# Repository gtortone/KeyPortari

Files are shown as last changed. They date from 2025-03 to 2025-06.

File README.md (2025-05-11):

# 🕹️⌨️ The KeyPortari a 2600/7800 Keyboard Interface

This project enables the connection of a PS/2 keyboard (or a USB keyboard that supports the PS/2 protocol) to the Atari 2600 or 7800 console. The ATmega328P processes keystrokes and controls the joystick inputs of the Atari 2600 accordingly.

## ✨ Features
- **PS/2 Keyboard Support**: Supports various keyboard layouts (DE, US, FR).
- **Direct ASCII Conversion**: Translates keystrokes into Atari 2600-compatible signals.
- **Configurable Keymaps**: Customizable key assignments for Atari 2600 control.
- **Efficient GPIO Usage**: Utilizes an 8-bit port for direct control.
- **Configurable DIP Switches**: 4-bit resistor-ladder circuit for easy configuration.

## 🔌 Hardware Requirements
- **ATmega328P 5V 16Mhz (Arduino-compatible)**
- **PS/2 Keyboard (or USB Keyboard that supports the PS/2 protocol)**
- **Resistors for Resistor-Ladder (10kΩ, 20kΩ, 40kΩ, 80kΩ, 100kΩ Pull-up)**
- **2x Quad analog switch (74HC4066)**
- **Joystick port connection for the Atari 2600**

## 🛠️ Sponsored by JLCPCB
PCB manufacturing for this project was kindly sponsored by [JLCPCB](https://jlcpcb.com/?from=KEYPORTARI) – a leading PCB prototype service.
For the first prototype run, [JLCPCB](https://jlcpcb.com/?from=KEYPORTARI) generously provided 15 SMD assembled test boards, helping to accelerate early hardware development.

If you’re a developer or hardware tinkerer and would like to experiment with the interface or contribute your own ideas, feel free to reach out to me via [AtariAge](https://forums.atariage.com/topic/380359-the-keyportari-a-keyboard-interface-for-the-atari-26007800/page/4/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) – I’d be happy to provide a board to support your work.

## 🧪 Breadboard Setup (one joystick forwarded)
Breadboard Setup with one joystick forwarded

## ⚙️ Installation & Setup
1. **Upload code to ATmega328P** (via Arduino IDE or AVRDUDE).
2. **Connect PS/2 keyboard** to the corresponding pins.
3. **Set DIP switches** for the desired configuration.
4. **Connect to the Atari 2600 joystick port**.

## 🎮 Usage
- Each keystroke on the PS/2 keyboard is translated into joystick controls for the Atari 2600.
- Modifier keys like `Shift`, `Ctrl`, and `Alt` influence the key output (e.g., uppercase/lowercase characters).
- DIP switches can be used to activate different keyboard layout (US,DE,FR) configurations.

## 🐞 Known Issues & Solutions

## 🙏 Credits
- Project discussion: [AtariAge Forum](https://forums.atariage.com/topic/380359-keyboard-interface-for-the-atari-2600/)
- Open-source libraries: PS/2 Keyboard Library (modified for this project)
- Steve Guidi's ["Basic Programming" protocol](https://github.com/SteveGuidi/video-companion-media/tree/main/2021.06.09%20-%20Atari%202600%20Keyboard)

## 📄 License
- Firmware is licensed under the [MIT License](LICENSE)
- Hardware designs (schematics, PCB) are under the [CERN Open Hardware Licence v2.0 - Permissive](LICENSE-HARDWARE)

---
If you have any questions or suggestions, feel free to open an issue on GitHub! 🎮

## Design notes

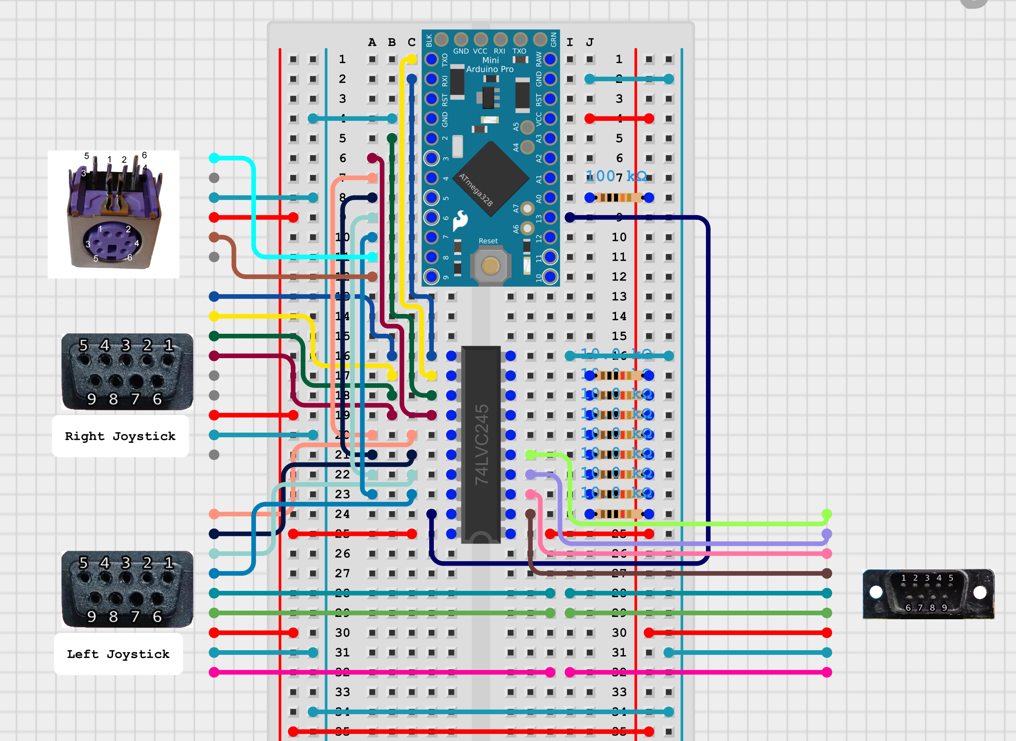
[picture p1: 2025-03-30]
docs/Breadboard_v1.png

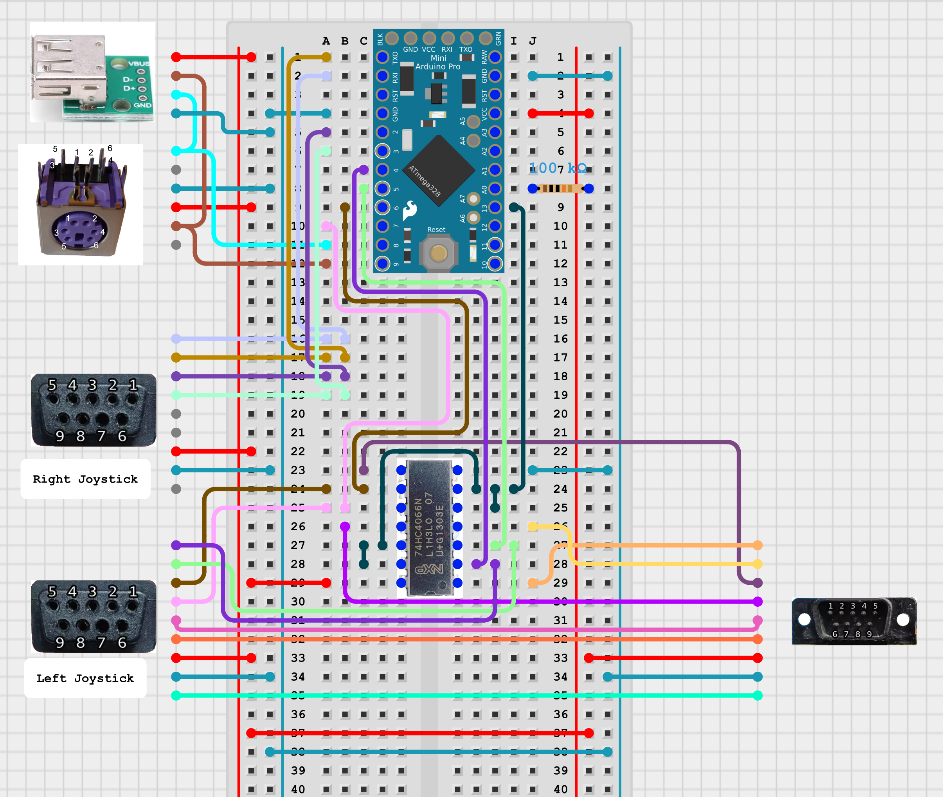
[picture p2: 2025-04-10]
docs/Breadboard_v3.png

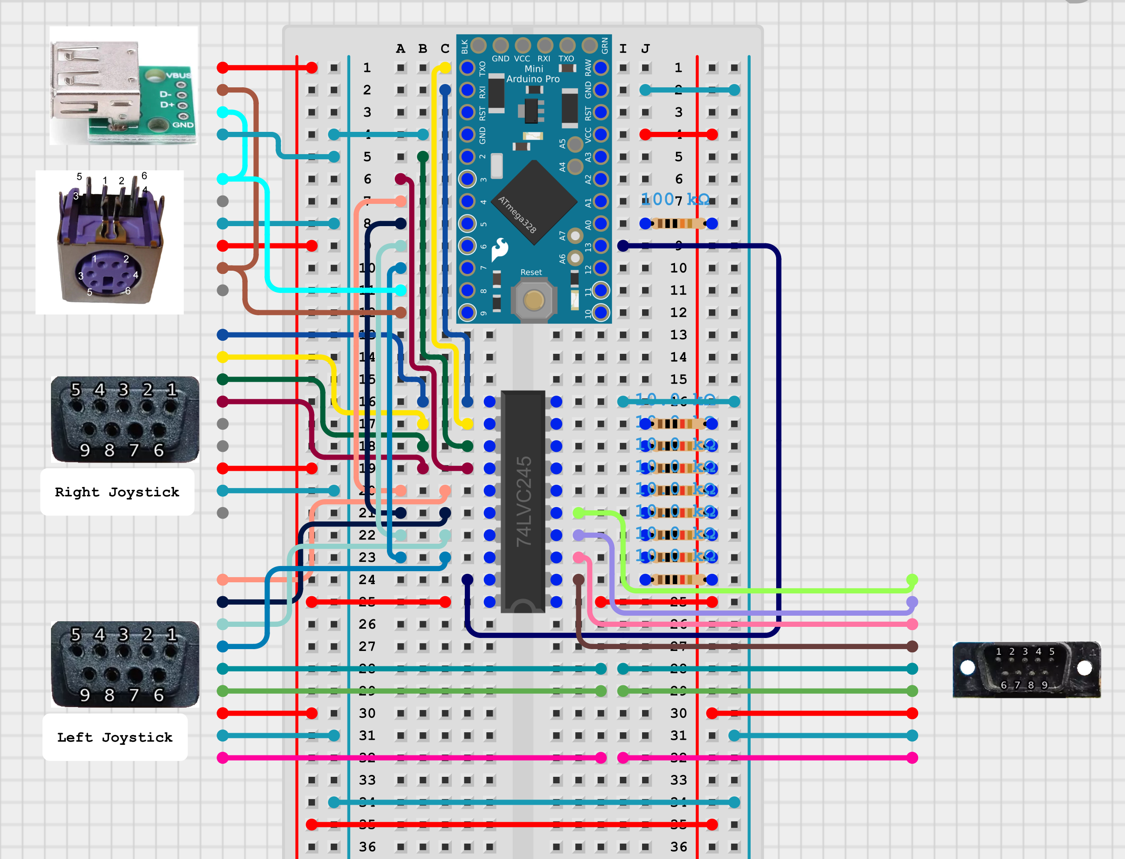
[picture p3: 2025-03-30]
docs/Breadboard_v2.png

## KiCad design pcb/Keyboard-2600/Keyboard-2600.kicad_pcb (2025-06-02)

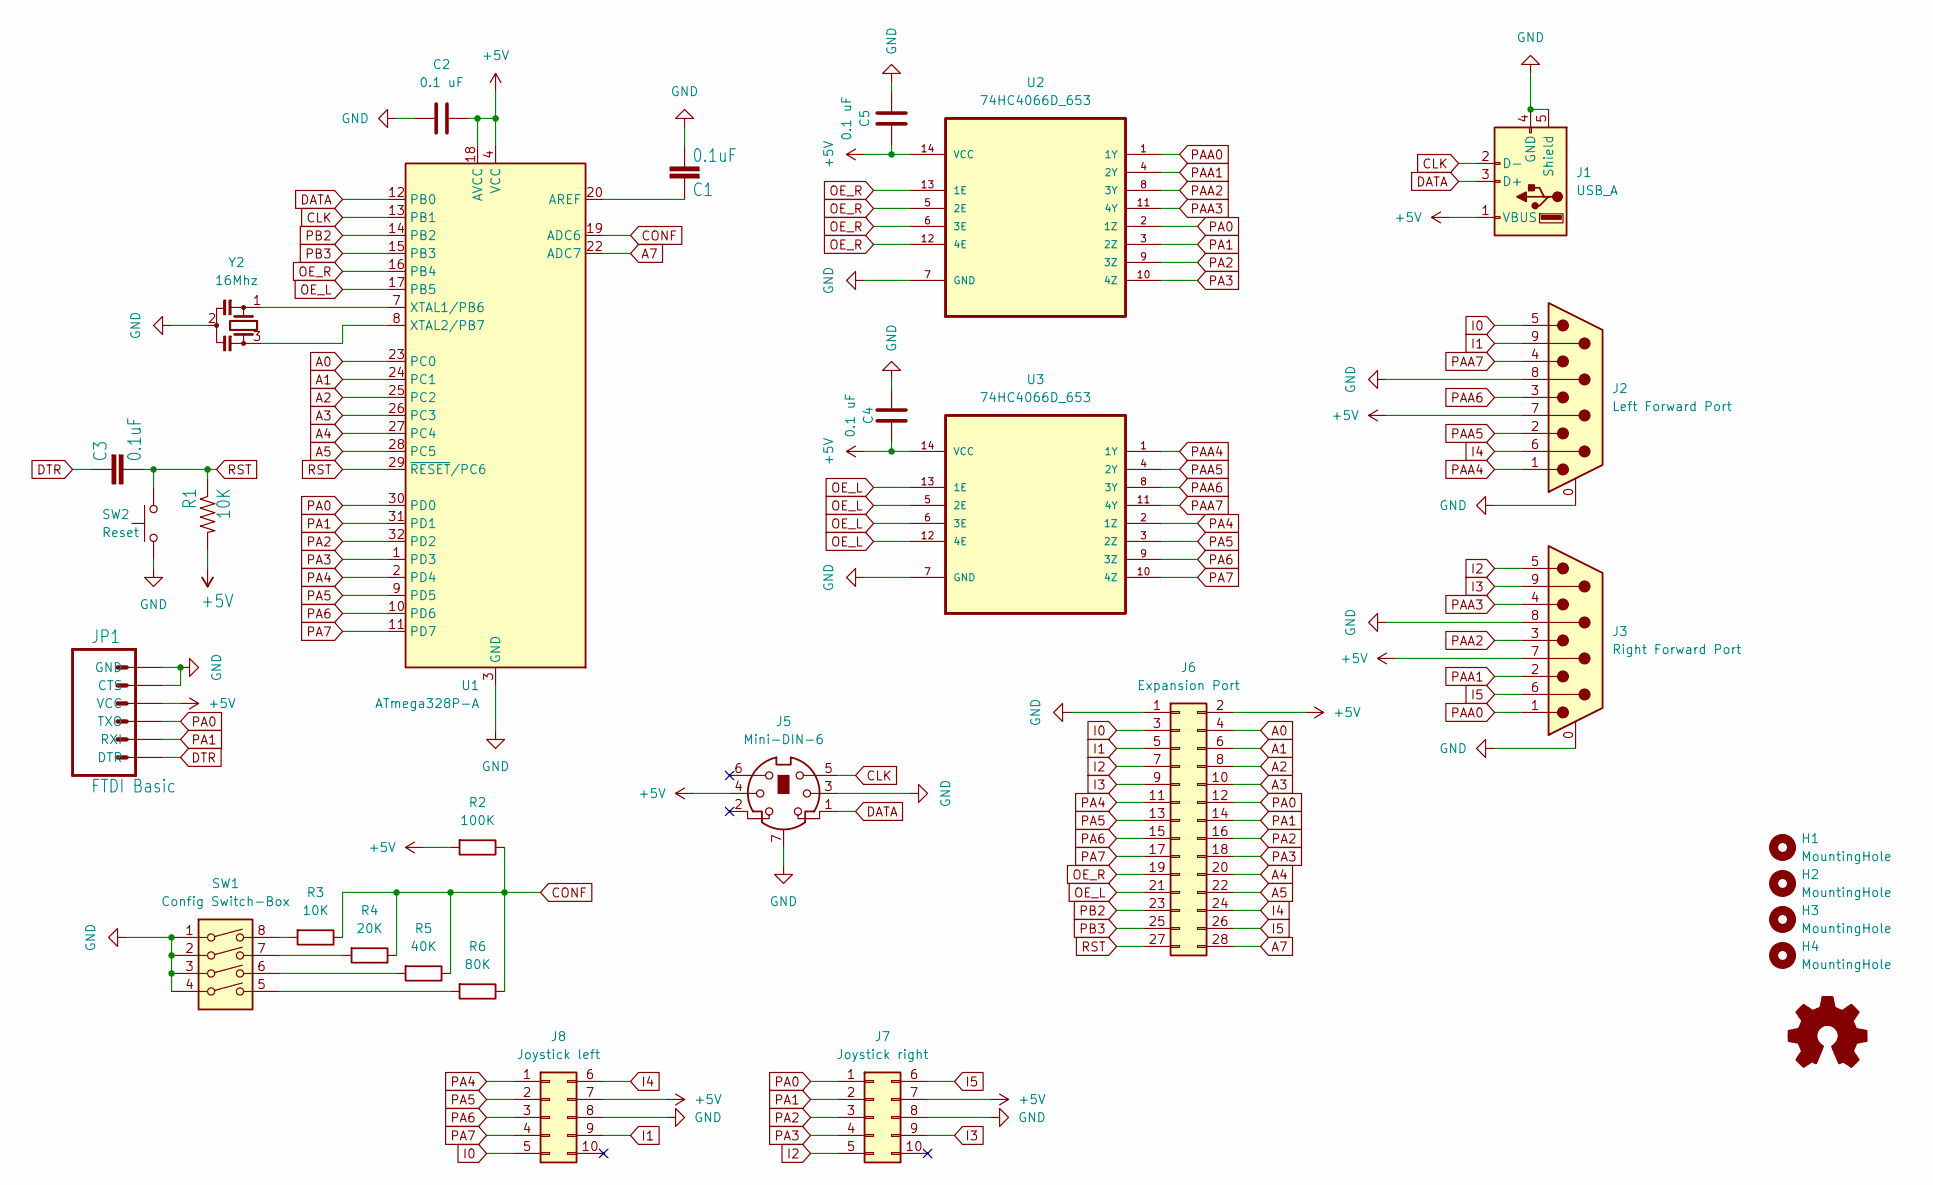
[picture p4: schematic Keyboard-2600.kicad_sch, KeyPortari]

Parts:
C1, C3: 0.1uF; C_0402_1005Metric
C2, C4, C5: 0.1 uF; C_0402_1005Metric
H1, H2, H3, H4: MountingHole; MountingHole_3mm
J1: USB_A; USB_A_Molex_67643_Horizontal
J2: Left Forward Port; DSUB-9_Male_Horizontal_P2.77x2.84mm_EdgePinOffset4.94mm_Hou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
J3: Right Forward Port; DSUB-9_Male_Horizontal_P2.77x2.84mm_EdgePinOffset4.94mm_Hou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
J5: Mini-DIN-6; Connector_Mini-DIN_Female_6Pin_2rows
J6: Expansion Port; PinHeader_2x14_P2.54mm_Vertical_KeyPortari_Expansion-Port
J7: Joystick right; PinHeader_2x05_P2.54mm_Vertical
J8: Joystick left; PinHeader_2x05_P2.54mm_Vertical
JP1: FTDI Basic; PinHeader_1x06_P2.54mm_Horizontal
R1, R3: 10K; R_0402_1005Metric
R2: 100K; R_0402_1005Metric
R4: 20K; R_0402_1005Metric
R5: 40K; R_0603_1608Metric
R6: 80K; R_0603_1608Metric
SW1: Config Switch-Box; SW_DIP_SPSTx04_Piano_10.8x11.72mm_W7.62mm_P2.54mm
SW2: Reset; SW_Push_1P1T_NO_CK_KMR2
U1: ATmega328P-A; TQFP-32_7x7mm_P0.8mm
U2, U3: 74HC4066D_653; SOIC-14_3.9x8.7mm_P1.27mm; MPN 74HC4066D,653
Y2: 16Mhz; Resonator_SMD_Murata_CSTxExxV-3Pin_3.0x1.1mm

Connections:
+5V: C2.2, C4.2, C5.2, J1.1 (VBUS), J2.7, J3.7, J5.4, J6.2, J7.7, J8.7, JP1.4 (VCC), R1.2, R2.2, U1.4 (VCC), U1.6 (VCC), U1.18 (AVCC), U2.14 (VCC), U3.14 (VCC)
A0: J6.4, U1.23 (PC0)
A1: J6.6, U1.24 (PC1)
A2: J6.8, U1.25 (PC2)
A3: J6.10, U1.26 (PC3)
A4: J6.20, U1.27 (PC4)
A5: J6.22, U1.28 (PC5)
A7: J6.28, U1.22 (ADC7)
CLK: J1.2 (D-), J5.5, U1.13 (PB1)
CONF: R2.1, R3.1, R4.1, R5.1, R6.1, U1.19 (ADC6)
DATA: J1.3 (D+), J5.1, U1.12 (PB0)
DTR: C3.2, JP1.1 (DTR)
GND: C1.1, C2.1, C4.1, C5.1, J1.4 (GND), J1.5 (Shield), J2.0 (PAD), J2.8, J3.0 (PAD), J3.8, J5.3, J5.7, J6.1, J7.8, J8.8, JP1.5 (CTS), JP1.6 (GND), SW1.1, SW1.2, SW1.3, SW1.4, SW2.1, U1.3 (GND), U1.5 (GND), U1.21 (GND), U2.7 (GND), U3.7 (GND), Y2.2
I0: J2.5, J6.3, J8.5
I1: J2.9, J6.5, J8.9
I2: J3.5, J6.7, J7.5
I3: J3.9, J6.9, J7.9
I4: J2.6, J6.24, J8.6
I5: J3.6, J6.26, J7.6
unnamed: R3.2, SW1.8
unnamed: R4.2, SW1.7
unnamed: R5.2, SW1.6
unnamed: R6.2, SW1.5
unnamed: C1.2, U1.20 (AREF)
unnamed: U1.7 (XTAL1/PB6), Y2.1
unnamed: U1.8 (XTAL2/PB7), Y2.3
OE_L: J6.21, U1.17 (PB5), U3.5 (2E), U3.6 (3E), U3.12 (4E), U3.13 (1E)
OE_R: J6.19, U1.16 (PB4), U2.5 (2E), U2.6 (3E), U2.12 (4E), U2.13 (1E)
PA0: J6.12, J7.1, JP1.3 (TXO), U1.30 (PD0), U2.2 (1Z)
PA1: J6.14, J7.2, JP1.2 (RXI), U1.31 (PD1), U2.3 (2Z)
PA2: J6.16, J7.3, U1.32 (PD2), U2.9 (3Z)
PA3: J6.18, J7.4, U1.1 (PD3), U2.10 (4Z)
PA4: J6.11, J8.1, U1.2 (PD4), U3.2 (1Z)
PA5: J6.13, J8.2, U1.9 (PD5), U3.3 (2Z)
PA6: J6.15, J8.3, U1.10 (PD6), U3.9 (3Z)
PA7: J6.17, J8.4, U1.11 (PD7), U3.10 (4Z)
PAA0: J3.1, U2.1 (1Y)
PAA1: J3.2, U2.4 (2Y)
PAA2: J3.3, U2.8 (3Y)
PAA3: J3.4, U2.11 (4Y)
PAA4: J2.1, U3.1 (1Y)
PAA5: J2.2, U3.4 (2Y)
PAA6: J2.3, U3.8 (3Y)
PAA7: J2.4, U3.11 (4Y)
PB2: J6.23, U1.14 (PB2)
PB3: J6.25, U1.15 (PB3)
RST: C3.1, J6.27, R1.1, SW2.2, U1.29 (~RESET/PC6)

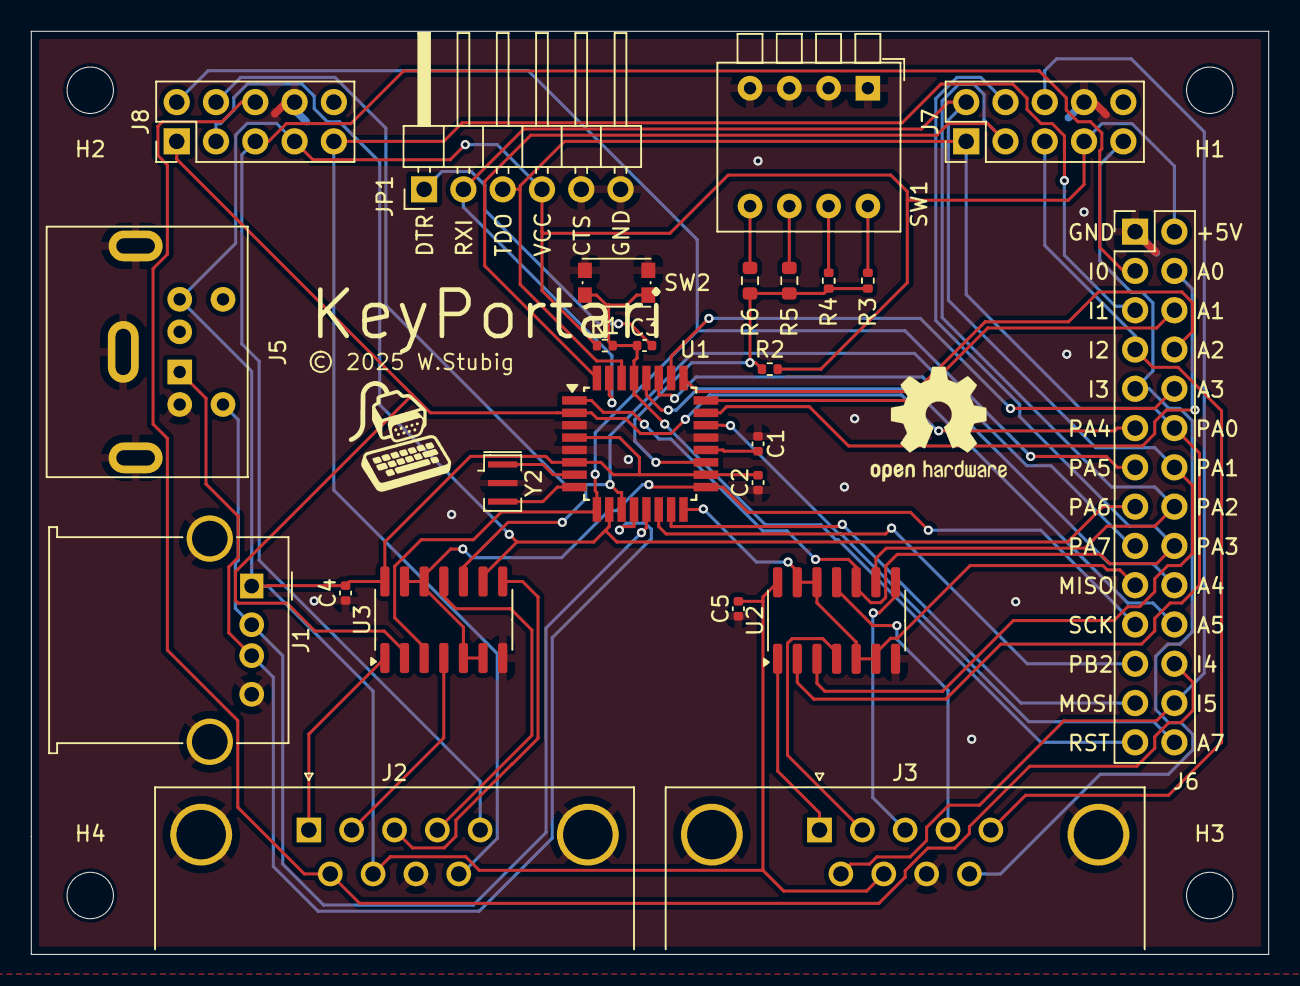
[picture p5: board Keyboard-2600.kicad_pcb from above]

Board: 2 copper layers, 80.0 x 59.7 mm, 29 parts (0 on the bottom side), 47 nets.

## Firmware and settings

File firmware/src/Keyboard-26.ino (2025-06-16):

/*

todo:
 - Init process !
 - Add TJs ASCII mapping
 - I2C protocol ?

*/

#include "PS2Keymaps.h"
#include "global.h"
#include "protocols/disabled_both_none.h"
#include "protocols/parallel_both_24char.h"
#include "protocols/parallel_both_BasicProgramming.h"
#include "protocols/parallel_both_CompuMate.h"


const PS2Keymap_t *keymap;
uint8_t activeProtocol;

enum InitState {
  INIT_IDLE,
  INIT_WAIT_FOR_FFFF,
  INIT_WAIT_FOR_ZERO_AGAIN,
  INIT_WAIT_FOR_PROTOCOL
};

typedef struct {
  int adc_threshold;
  uint8_t id;
} AdcMapping;

const AdcMapping adc_mappings[] PROGMEM = {
  {  52, 15}, { 55,  7}, { 59, 11},
  {  64,  3}, { 70, 13}, { 77,  5},
  {  86,  9}, { 97,  1}, {111, 14},
  { 129,  6}, {154, 10}, {192,  2},
  { 253, 12}, {373,  4}, {739,  8},
  {1024, 0}
};

void (*protocol_setup[])() = {
  protocol_disabled_both_none_setup,   protocol_parallel_both_24char_setup, protocol_parallel_both_BasicProgramming_setup, protocol_parallel_both_CompuMate_setup,
  protocol_parallel_both_24char_setup, protocol_parallel_both_24char_setup, protocol_parallel_both_24char_setup, protocol_parallel_both_24char_setup,
  protocol_parallel_both_24char_setup, protocol_parallel_both_24char_setup, protocol_parallel_both_24char_setup, protocol_parallel_both_24char_setup,
  protocol_parallel_both_24char_setup, protocol_parallel_both_24char_setup, protocol_parallel_both_24char_setup, protocol_parallel_both_24char_setup
};

void (*key_down[])(char) = {
  protocol_disabled_both_none_keyDown,   protocol_parallel_both_24char_keyDown, protocol_parallel_both_BasicProgramming_keyDown, protocol_parallel_both_CompuMate_keyDown,
  protocol_parallel_both_24char_keyDown, protocol_parallel_both_24char_keyDown, protocol_parallel_both_24char_keyDown, protocol_parallel_both_24char_keyDown,
  protocol_parallel_both_24char_keyDown, protocol_parallel_both_24char_keyDown, protocol_parallel_both_24char_keyDown, protocol_parallel_both_24char_keyDown,
  protocol_parallel_both_24char_keyDown, protocol_parallel_both_24char_keyDown, protocol_parallel_both_24char_keyDown, protocol_parallel_both_24char_keyDown
};

void (*key_up[])() = {
  protocol_disabled_both_none_keyUp,   protocol_parallel_both_24char_keyUp, protocol_parallel_both_BasicProgramming_keyUp, protocol_parallel_both_CompuMate_keyUp,
  protocol_parallel_both_24char_keyUp, protocol_parallel_both_24char_keyUp, protocol_parallel_both_24char_keyUp, protocol_parallel_both_24char_keyUp,
  protocol_parallel_both_24char_keyUp, protocol_parallel_both_24char_keyUp, protocol_parallel_both_24char_keyUp, protocol_parallel_both_24char_keyUp,
  protocol_parallel_both_24char_keyUp, protocol_parallel_both_24char_keyUp, protocol_parallel_both_24char_keyUp, protocol_parallel_both_24char_keyUp
};

void set_right_nibble(char value){
  // this might be moved to a protocol later
  // 1. set right SN74HC4066 to OE off !
  // 2. set right data port to output
  // 3. set right data port to keyvalue
  digitalWrite(OE_RIGHT_PORT, LOW);
  DDRD = 0b00001111;
  PORTD = value & 0x0F;
}

uint8_t map_adc_value(int adc_value) {
  int i = 0;
  while (i < 16 && (int) (pgm_read_word(&adc_mappings[i].adc_threshold)) < adc_value ) {
      i++;
  }
  return pgm_read_byte(&adc_mappings[i].id); 
}

void setup() {

  #if DEBUG
  Serial.begin(115200);
  #endif

  pinMode(CLOCK, INPUT_PULLUP); // For most keyboards the builtin pullups are sufficient, so the 10k pullups can be omitted
  pinMode(DATA, INPUT_PULLUP);
  pinMode(OE_LEFT_PORT, OUTPUT);
  pinMode(OE_RIGHT_PORT, OUTPUT);
  // Disable joystick forwarding via both 74HC4066 (protocol setup may enable it later)
  digitalWrite(OE_LEFT_PORT, LOW);
  digitalWrite(OE_RIGHT_PORT, LOW);

  bitSet(PCICR, PCIE0);   // Enable pin change interrupts on pin B0-B7
  bitSet(PCMSK0, PCINT1); // Pin change interrupt on Clock pin (PCINT1 = PB1 Arduino Pin 9)

  int adcValue = analogRead(DIP_A_PIN);  // Read voltage of DIP-Switch block resistor ladder (0-1023)
  uint8_t dipConfig = map_adc_value(adcValue); 

  switch (dipConfig & 0b11) { // lower 2 bits of dipConfig define keyboard layout
    case 0b01: keymap = &PS2Keymap_German;      break;
    case 0b10: keymap = &PS2Keymap_French;      break;
    default: keymap = &PS2Keymap_US;            break;
  }

  activeProtocol = (dipConfig >> 2) & 0b11;

  #if DEBUG
  Serial.println("Keyboard test");
  Serial.println(adcValue);
  Serial.println(dipConfig);
  #else
  protocol_setup[activeProtocol]();
  #endif
}

volatile uint8_t curscan = 0;
volatile bool keyboard_action = false;

ISR(PCINT0_vect) {
  uint16_t newscan = 0;
  for(int i = 0; i<11; i++) {
    while(digitalRead(CLOCK));
    newscan |= digitalRead(DATA) << i;
    while(!digitalRead(CLOCK));
  }
  newscan >>= 1;
  newscan &= 0xFF;
  curscan = newscan;
  keyboard_action = true;
  bitSet(PCIFR, PCIF0);
}

void loop() {
 	static uint8_t keyboard_state = 0, lastscan = 0;
  //static InitState initState = INIT_IDLE;
  //static unsigned long initTimer = 0;

  char c;

  if(keyboard_action){
    keyboard_action = false;
    if(curscan != 0xF0 && curscan != 0xE0){
      if (curscan < PS2_KEYMAP_SIZE){
        if (keyboard_state & SHIFT) {
          c = pgm_read_byte(keymap->shift + curscan);
        } else if ((keyboard_state & ALTGR) && keymap->uses_altgr) {
          c = pgm_read_byte(keymap->altgr + curscan);
        } else {
          c = pgm_read_byte(keymap->noshift + curscan);
        }
      }

      if(lastscan == 0xF0){
        if (curscan == 0x12 || curscan == 0x59) {
          keyboard_state &= ~SHIFT;
        } else if (curscan == 0x11 && (keyboard_state & MODIFIER)) {
          keyboard_state &= ~ALTGR;
        } else {
          // Key up
          #if DEBUG
          Serial.print((int)c);
          Serial.println(" up");
          #else
          key_up[activeProtocol]();
          #endif
        }
        // CTRL, ALT & WIN keys could be added
        // but is that really worth the overhead?
        keyboard_state &= ~MODIFIER;
      }else{
        if (curscan == 0x12 || curscan == 0x59) {
          keyboard_state |= SHIFT;
        } else if (curscan == 0x11 && (keyboard_state & MODIFIER)) {
          keyboard_state |= ALTGR;
        } else {
          if(lastscan == 0xE0){ // MODIFIER
            switch (curscan) {
              case 0x70: c = PS2_INSERT;      break;
              case 0x6C: c = PS2_HOME;        break;
              case 0x7D: c = PS2_PAGEUP;      break;
              case 0x71: c = PS2_DELETE;      break;
              case 0x69: c = PS2_END;         break;
              case 0x7A: c = PS2_PAGEDOWN;    break;
              case 0x75: c = PS2_UPARROW;     break;
              case 0x6B: c = PS2_LEFTARROW;   break;
              case 0x72: c = PS2_DOWNARROW;   break;
              case 0x74: c = PS2_RIGHTARROW;  break;
              case 0x4A: c = '/';             break;
              case 0x5A: c = PS2_ENTER;       break;
              default: break;
            }
          }
          #if DEBUG
          Serial.print((int)c);
          Serial.println(" down");
          #else
          key_down[activeProtocol](c);
          #endif
        }
        keyboard_state &= ~MODIFIER;
      }
    }
    lastscan = curscan;
  }else{
/* // todo check active protocol is "soft" switchable
    uint8_t busState = PIND & 0x0F;
    switch (initState) {
      case INIT_IDLE:
        if (busState == 0) {
          initState = initState + 1;
          initTimer = millis();
        }
        break;

      case INIT_WAIT_FOR_FFFF:
        if (busState == 0b1111) {
          initState = initState + 1;
        }
        break;

      case INIT_WAIT_FOR_ZERO_AGAIN:
        if (busState == 0) {
          initState = initState + 1;
        }
        break;

      case INIT_WAIT_FOR_PROTOCOL:
        if (busState != 0) {
          activeProtocol = busState;
          initState = INIT_IDLE;

          delay(17);                        // wait one 60Hz-Frame
          set_right_nibble(activeProtocol); // return activeProtocol for confirmation on the bus
          delay(34);                        // wait two more frames
          protocol_parallel_both_24char_keyUp();
        }
        break;
    }

    // Timeout protection
    if (initState != INIT_IDLE && (millis() - initTimer > 1000)) {
      initState = INIT_IDLE;
    }
*/
  }
}

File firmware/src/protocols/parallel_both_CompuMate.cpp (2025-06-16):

/*
 from stella/src/emucore/CartCM.hxx
     SWCHA: D7 = Audio input from tape player
           D6 = Audio out to tape player and 4017 CLK
                1 -> increase key column (0 to 9)
           D5 = 4017 RST, and RAM direction. (high = write, low = read)
                1 -> reset key column to 0 (if D4 = 0)
                0 -> enable RAM writing (if D4 = 1)
           D4 = RAM enable: 1 = disable RAM, 0 = enable RAM
           D3 = keyboard row 3 input (0 = key pressed)
           D2 = keyboard row 1 input (0 = key pressed)
           D1 = bank select high bit
           D0 = bank select low bit

    INPT0: D7 = FUNC key input (0 on startup / 1 = key pressed)
    INPT1: D7 = always HIGH input (pulled high thru 20K resistor)
    INPT2: D7 = always HIGH input (pulled high thru 20K resistor)
    INPT3: D7 = SHIFT key input (0 on startup / 1 = key pressed)
    INPT4: D7 = keyboard row 0 input (0 = key pressed)
    INPT5: D7 = keyboard row 2 input (0 = key pressed)
*/

#include "protocols/parallel_both_CompuMate.h"

#define RAM _BV(PD4)
#define RST _BV(PD5)


volatile uint8_t my_4017_counter;

void protocol_parallel_both_CompuMate_setup(){
  // disable joystick port forwarding
  digitalWrite(OE_LEFT_PORT, LOW);
  digitalWrite(OE_RIGHT_PORT, LOW);

  // set port on RIOT bus to input/output.
  DDRD = 0b00001100;
  PORTD = 0b00001100; // inputs no pullups, outputs high
//  PORTD = 0b11111111; // activate pullups

  pinMode(INPT_0, OUTPUT);
  digitalWrite(INPT_0, LOW); // FUNC Key
  pinMode(INPT_1, OUTPUT);
  digitalWrite(INPT_1, HIGH);
  pinMode(INPT_2, OUTPUT);
  digitalWrite(INPT_2, HIGH);
  pinMode(INPT_3, OUTPUT);
  digitalWrite(INPT_3, LOW); // Shift key
  pinMode(INPT_4, OUTPUT);
  digitalWrite(INPT_4, HIGH); // row 0
  pinMode(INPT_5, OUTPUT);
  digitalWrite(INPT_5, HIGH); // row 2

  my_4017_counter = 0;

  cli();                    // globale Interrupts aus
  PCICR |= _BV(PCIE2);      // Pin-Change-Interrupts auf Port D aktivieren
  PCMSK2 |= _BV(PCINT21)    // nur PD5 (PCINT21)
         |  _BV(PCINT22);   // und PD6 (PCINT22) maskieren
  sei();                    // globale Interrupts an
}

void protocol_parallel_both_CompuMate_keyUp(){
  /* todo */
}
void protocol_parallel_both_CompuMate_keyDown(char value){
  uint8_t i = 0;

  const CompuMateKeyEntry* entry = getCompuMateKeyEntry(value);
  if (!entry) return;

  if(entry->shift){
      digitalWrite(INPT_3, HIGH); // Press SHIFT key
  }
  if(entry->func){
      digitalWrite(INPT_0, HIGH); // Press FUNC key
  }
//  while(i++ < 2 || !keyboard_action) { // do as long as key is not released, but at least two scans
  while(i++ < 4 ) { // do for 4 column scans
    while(my_4017_counter != entry->column) {}
    digitalWrite(entry->row, LOW);
//    while(my_4017_counter == entry->column) {} //&& !keyboard_action) {}
    // Wait for 4017 reset on SWCHA_6
    // The compuMate ROM resets the 4017 if he has found a pressd key?
    // while (!(PIND & _BV(PD5))) { /* no-op */ } // wait for RST PD5 going high
    // while (!(PIND & _BV(PD6))) { /* no-op */ } // wait for CLK PD6 LOW→HIGH
    while (!(PIND & RST) || !(PIND & RAM)) { /* no-op */ }
  //    b) dann bis PD5==0 oder PD4==0, das Ende der Column
//    while  ((PIND & RST) &&  (PIND & RAM)) { /* no-op */ }

    digitalWrite(entry->row, HIGH);
  }
  if(entry->shift){
    digitalWrite(INPT_3, LOW); // Release SHIFT key
  }
  if(entry->func){
    digitalWrite(INPT_0, LOW); // Release FUNC key
  }
//  keyboard_action = false; // toDo should be done in main loop

}

ISR(PCINT2_vect) {
  static bool last5 = false, last6 = false;
  uint8_t currPortD = PIND;         // Port-D-Pins einlesen

  // PD5: SWCHA Bit 5
  bool now5  = currPortD & _BV(PD5);
  if (!last5 && now5 && (currPortD & _BV(PD4))) {
      my_4017_counter = 0;
  }

  // PD6: SWCHA Bit 6
  bool now6  = currPortD & _BV(PD6);
  if (!last6 && now6 && !now5){
    if(++my_4017_counter > 9){
      my_4017_counter = 0;
    }
  }

  last5 = now5;
  last6 = now6;

  // Interrupt-Flag für Port D löschen:
  bitSet(PCIFR, PCIF2);
}

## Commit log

2025-03-28 Just pushing current state before cleanup
2025-03-29 Add keycodes maping spreadsheet
    [Keycodes-ASCII.ods]
2025-03-30 Add USB host connector to breadboard
2025-04-19 Schematics and PCB layout. KiCAD 8.0
    [Keyboard-2600.kicad_pcb, Keyboard-2600.kicad_sch]
2025-05-10 Test board WIP state.
    [Keyboard-2600.kicad_pcb, Keyboard-2600.kicad_sch]
2025-05-26 Fix DIP-Switch mapping
2025-06-01 Fix PROGMEM, Move enabling of 4066 to protocols
    [Keyboard-26.ino]

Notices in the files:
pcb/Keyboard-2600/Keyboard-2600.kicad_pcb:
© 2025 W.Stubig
